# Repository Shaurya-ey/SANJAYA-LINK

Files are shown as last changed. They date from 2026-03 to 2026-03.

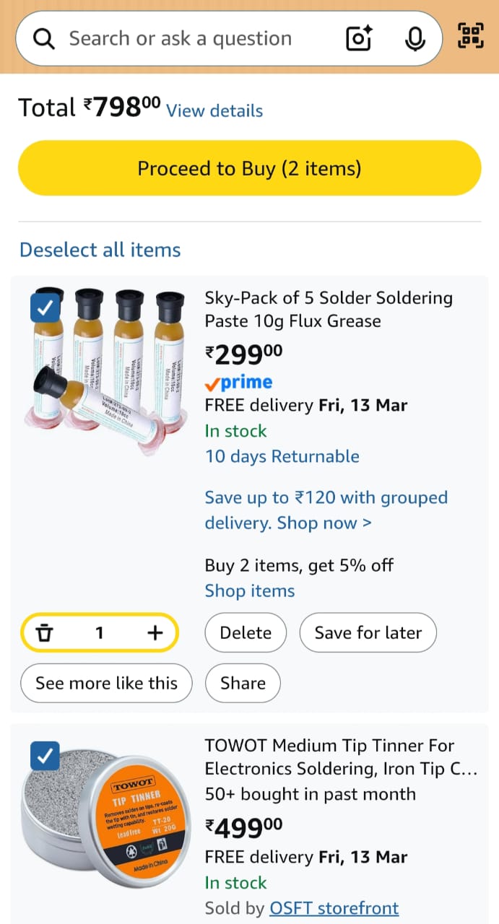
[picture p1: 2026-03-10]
Cart/amazon1.jpeg

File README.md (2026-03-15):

<h1 align="center">SANJAYA-LINK</h1>

<p align="center">
pcbfront 
pcbback
cad

</p>
 
 ---

 # 1. Overview

SANJAYA-LINK is a custom 1-Watt telemetry and control system built for drones, fixed-wing UAVs, and RC models. While ELRS and crossfire modules are great, I wanted a transparent, fully customizable dev like board based on the RP2040 and SX1262 that I could integrate directly into my own flight controllers and ground stations.

## Features
- **RP2040** – Dual-core Cortex-M0+ microcontroller running up to 133 MHz. It handles all logic and communication.
- **SX1262** – LoRa transceiver for long-range, low-power wireless communication (EU bands).
- **0900FM15K0039001E** – RF crystal oscillator for stable timing.
- **W25Q128JVS** – 128 Mbit SPI flash memory for additional storage.
- **AP2112K-3.3** – 3.3V voltage regulator.
- **PE4259** – RF switch between antenna and transceiver.
- **Status LEDs** – For easier debugging or indication.
- **Dimensions:** - 51.82mm x 48.39mm

## What it is 
This is a custom-built, compact board that pairs the **RP2040 processor** with an **SX1262 LoRa radio**.
Basically, it's a long-range wireless communicator (through Radio Signals). I designed it to be a simple way to send data over long distances without needing Wi-Fi or any other mediums.

## Why I Made This Project
I was searching a solution for telemetery of data for my upcoming **Drone** and **Model Rocketry** ideas. Then i got deep into this idea and after researching a lot i found it intresting and do-able, and decided to build this from scratch. I’ve spent a lot of time debugging things like the clock settings and power rails to make sure it actually stays running on a battery which was hectic.

## How To Use
- **Connect:** Plug the module into your computer via the USB-C port to load your code.
- **Power:** You can run it off a battery or the USB supply; I’ve included a regulator to keep the power clean and stable.
- **Lesss Goo** Just write your script, upload it, and watch it start communicating over the LoRa network.

---

# 2. Layouts

## Schematics
Schematic

## PCB

PCBrouted

## Case And Assembly

<p align="center">



---

# 3. BOM (Bill Of Materials)

| Item | Description | Quantity | Total Price (USD) | URL |
|---|---|---|---|-----|
| 100nF 0402 Capacitor | Ceramic capacitor 100nF 0402 package | 24 | 0.18 |https://robu.in/product/gcm155l8eh104ke07d-murata-electronics-50v-100nf-x8l-%c2%b110-0402-multilayer-ceramic-capacitors-mlcc-smd-smt-rohs/ |
| 1uF 0402 Capacitor | Ceramic capacitor 1uF 0402 package | 4 | 0.40 |https://www.digikey.in/en/products/detail/murata-electronics/GRM155R61H105ME05D/12091059 |
| 15pF 0402 Capacitor | Ceramic capacitor 15pF 0402 package | 5 | 0.12 |https://robu.in/product/gjm1555c1h150fb01d-murata-electronics-50v-15pf-c0g-%c2%b11-0402-multilayer-ceramic-capacitors-mlcc-smd-smt-rohs/ |
| 10uF 0402 Capacitor | Ceramic capacitor 10uF 0402 package | 4 | 1.04 | https://www.digikey.in/en/products/detail/murata-electronics/GRT155R61A106ME13D/19115561|
| 1nF 0402 Capacitor | Ceramic capacitor 1nF 0402 package | 2 | 0.28 |https://www.digikey.in/en/products/detail/kemet/C0402C102K5GECAUTO7411/8648675 |
| 39pF 0402 Capacitor | Ceramic capacitor 39pF 0402 package | 2 | 0.20 |https://www.digikey.in/en/products/detail/murata-electronics/GCM1555C1H390JA16J/4903596 |
| 3.3pF 0402 Capacitor | Ceramic capacitor 3.3pF 0402 package | 4 | 0.40 | https://www.digikey.in/en/products/detail/murata-electronics/GJM1555C1H3R3CB01D/702288|
| 470nF 0402 Capacitor | Ceramic capacitor 470nF 0402 package | 2 | 0.22 |https://www.digikey.in/en/products/detail/murata-electronics/GRM155R61A474KE15D/702528 |
| 47pF 0402 Capacitor | Ceramic capacitor 47pF 0402 package | 4 | 0.12 |https://robu.in/product/gcm1555c1h470fa16d-murata-electronics-50v-47pf-c0g-%c2%b11-0402-multilayer-ceramic-capacitors-mlcc-smd-smt-rohs/ |
| Blue LED 0402 | Blue indicator LED | 2 | 0.38 |https://www.digikey.in/en/products/detail/w%C3%BCrth-elektronik/150080BS75000/4489912 |
| Red LED 0402 | Red indicator LED | 2 | 0.38 |https://www.digikey.in/en/products/detail/w%C3%BCrth-elektronik/150080SS75000/4489921 |
| BLM15AX102SN1D | Ferrite bead 1kΩ @100MHz 0402 | 2 | 0.20 | https://www.digikey.in/en/products/detail/murata-electronics/BLM15AX102SN1D/2256877|
| 0900FM15K0039001E | LoRa RF front-end filter | 2 | 0.90 |https://www.digikey.in/en/products/detail/johanson-technology-inc/0900FM15K0039001E/16639329 |
| USB-C Port | USB Type-C receptacle | 2 | 1.54 |https://www.digikey.in/en/products/detail/gct/USB4105-GF-A/11198441 |
| SMA Connector | RF antenna connector | 2 | 6.56 |https://www.digikey.in/en/products/detail/taoglas-limited/EMPCB-SMAFSTJ-B-HT/3522337 |
| 15uH 0402 Inductor | Power inductor 15uH | 2 | 0.12 |https://www.digikey.in/en/products/detail/murata-electronics/LQW15DN150M00D/9559544 |
| 47nH 0402 Inductor | RF inductor 47nH | 2 | 0.20 | https://www.digikey.in/en/products/detail/murata-electronics/LQG15WH47NJ02D/11690059|
| 9.1nH 0402 Inductor | RF inductor 9.1nH | 4 | 0.13 |https://robu.in/product/lqw15an9n1g00d-murata-wirewound-inductor-9-1-nh-0-14-ohm-5-5-ghz-540-ma-0402-1005-metric-lqw15a_00/ |
| 100Ω 0402 Resistor | Resistor 100Ω | 2 | 0.20 | https://www.digikey.in/en/products/detail/yageo/RC0402FR-10100RL/16982189|
| 10kΩ 0402 Resistor | Resistor 10kΩ | 2 | 0.20 |https://www.digikey.in/en/products/detail/yageo/RT0402FRD0710KL/5926329 |
| 27.4Ω 0402 Resistor | Resistor 27.4Ω | 4 | 0.40 |https://www.digikey.in/en/products/detail/bourns-inc/CR0402-FX-27R4GLF/3783281 |
| 1kΩ 0402 Resistor | Resistor 1kΩ | 8 | 0.79 |https://www.digikey.in/en/products/detail/yageo/RC0402FR-071KL/726513 |
| 5.1kΩ 0402 Resistor | Resistor 5.1kΩ | 4 | 0.40 |https://www.digikey.in/en/products/detail/yageo/RC0402FR-135K1L/14286364 |
| Tactile Switch | Reset / Boot tactile switch | 4 | 0.88 |https://www.digikey.in/en/products/detail/same-sky-formerly-cui-devices/TS09-63-25-WT-260-SMT-TR/15839064 |
| SX1262IMLTRT | LoRa transceiver IC | 2 | 6.22 |https://robu.in/product/sx1262imltrt-semitech-300kbps-general-purposeism1ghz-spi-qfn-24-ep4x4-rf-transceiver-ics-rohs/ |
| RP2040 | Microcontroller | 2 | 1.74 |https://robu.in/product/raspberry-pi-rp2040/ |
| W25Q64JVSSIQ | SPI Flash memory | 2 | 4.40 |https://robu.in/product/w25q64jvssiq-winbond-elec-sop-8-208mil-nor-flash-rohs/ |
| AP2127K-3.3 | 3.3V LDO regulator | 2 | 0.38 |https://www.digikey.in/en/products/detail/diodes-incorporated/AP2127K-3-3TRG1/4470786 |
| RF Switch SPDT | RF switch SC70-6 | 2 | 1.56 |https://www.digikey.in/en/products/detail/psemi/4259-63/2614473 |
| 32MHz Crystal | System clock crystal | 2 | 0.88 | https://robu.in/product/yxc-ysx221sl-32mhz-12pf-20ppm-4pad-smd-smt-crystal/|
| 12MHz Crystal | System clock crystal | 2 | 0.40 |https://robu.in/product/ysx321sl-12mhz-10pf-10ppm-4pins-smd-smt-metal-surface-quartz-crystal-pack-of-2/ |
| Schottky Diode | Fast switching diode | 2 | 0.46 |https://www.digikey.in/en/products/detail/mcc-micro-commercial-components/MBR0520-TP/717250 |
| USBLC6-2SC6 | USB ESD protection | 2 | 0.70 | https://www.digikey.in/en/products/detail/stmicroelectronics/USBLC6-2SC6/1040559|
| TPD1E05U06 | ESD protection diode | 2 | 0.70 | https://www.digikey.in/en/products/detail/texas-instruments/TPD1E05U06DPYR/3844805|
| MF-MSMF050 | Resettable fuse | 2 | 1.02 | https://www.digikey.in/en/products/detail/bourns-inc/MF-MSMF050-30X-2/15926789|
| Header Pins | Pin headers | 2 | 0.13 |https://robu.in/product/2-54mm-1x40-pin-male-single-row-straight-short-header-strip-pack-of-3/ |
| 865–868MHz Antenna | Rubber duck antenna | 1 | 0.69 | https://robu.in/product/865-868mhz-1-8-dbi-gain-rubber-duck-antenna/|
| Solder Wire | Soldering wire | 1 | 3.30 | https://robu.in/product/soldering-wire-1-mm-100g/|
| Soldering Flux | Flux for soldering | 1 | 3.24 |https://www.amazon.in/dp/B08VHD1VS1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 |
| Tip Tinner | Soldering tip cleaner | 1 | 5.41 |https://www.amazon.in/dp/B09BQRQ9JF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 |
| Hot Air Station | YIHUA 8858-IV portable | 1 | 25.09 |https://robu.in/product/yihua-8858-iv-portable-hot-air-station/ |
| PCB Manufacturing + 3-D Printing | Printed circuit board + 3d printing | 1 | 24.14 + 2 | |
| 2.5x10mm Screws | Screws for Case | 1 | 1.52 | https://robu.in/product/easymech-ss-304-csk-countersunk-philips-head-m2-5-x-6-mm-bolt-25-pcs/ |
| **Shipping** | **Shipping fee** | 1 | 13.01 | |
| **TOTAL** |  |  | **116.17 USD** | |

# Note:
- I want some Soldering items + Heat gun for Soldering SMD components (as Assembly as a option for PCB Manufacturing is very costly + there will be hefty custom fees on them for 2 assembled boards), that i've included in BOM.
- I've included everything including Total Shipping Fee and Cart screen shots in the BOM.
- I'm building 2 LoRa boards so that i can verify and use them in my future projects.

**Thank You!!**

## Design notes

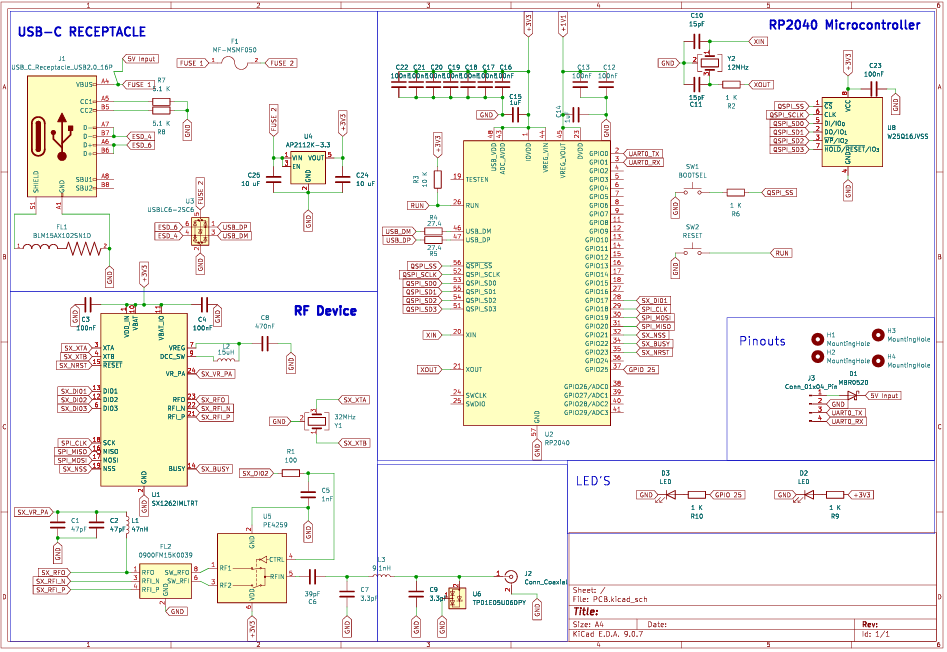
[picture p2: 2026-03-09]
Schematic.PNG

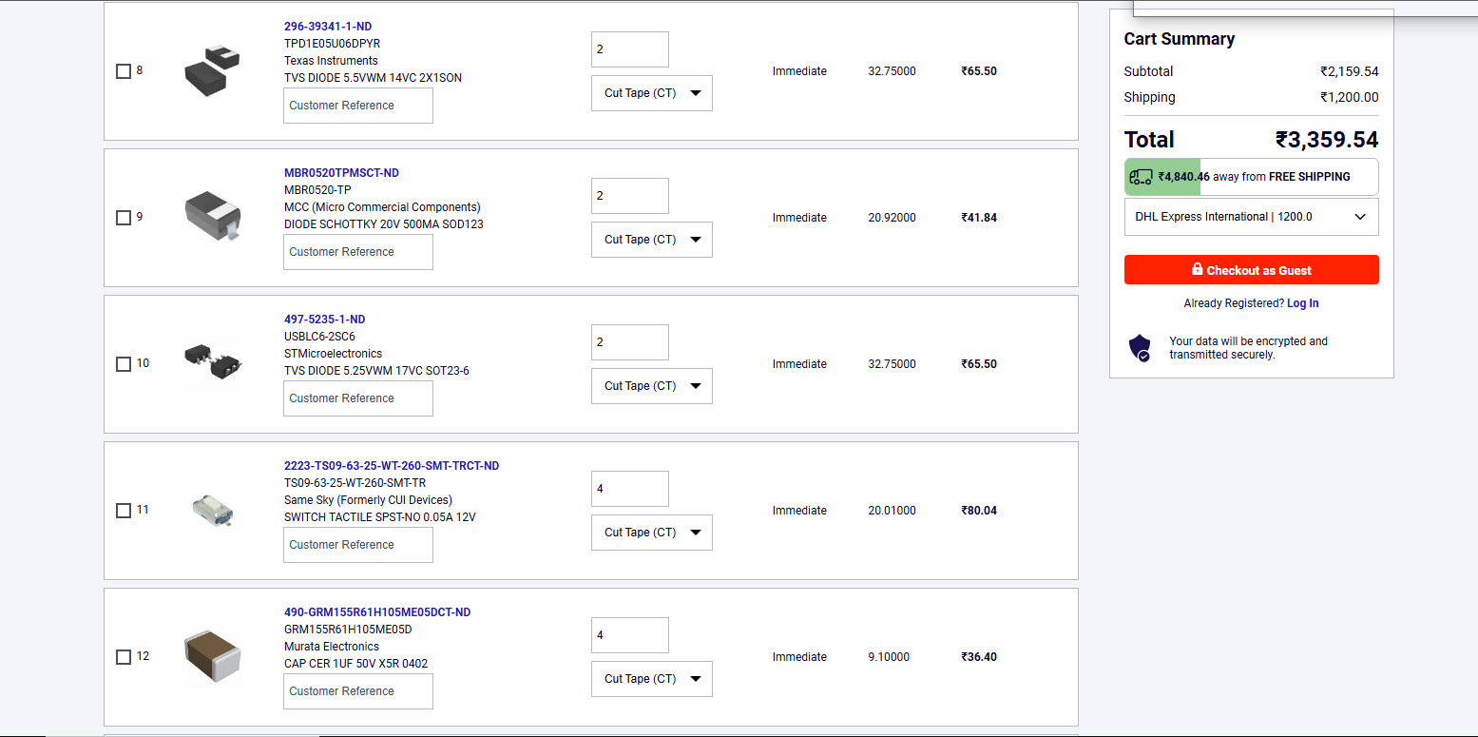
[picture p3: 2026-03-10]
Cart/d3.PNG

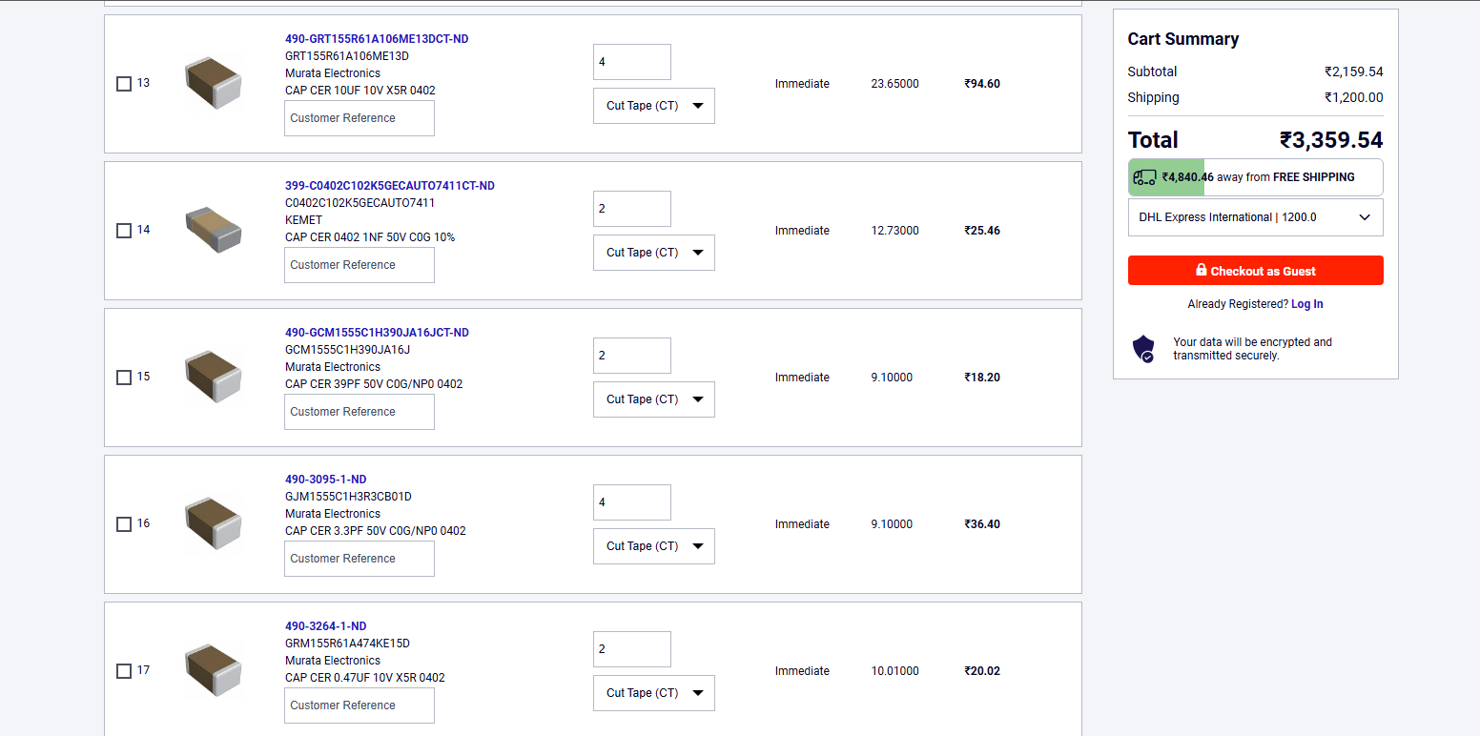
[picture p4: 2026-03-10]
Cart/d4.PNG

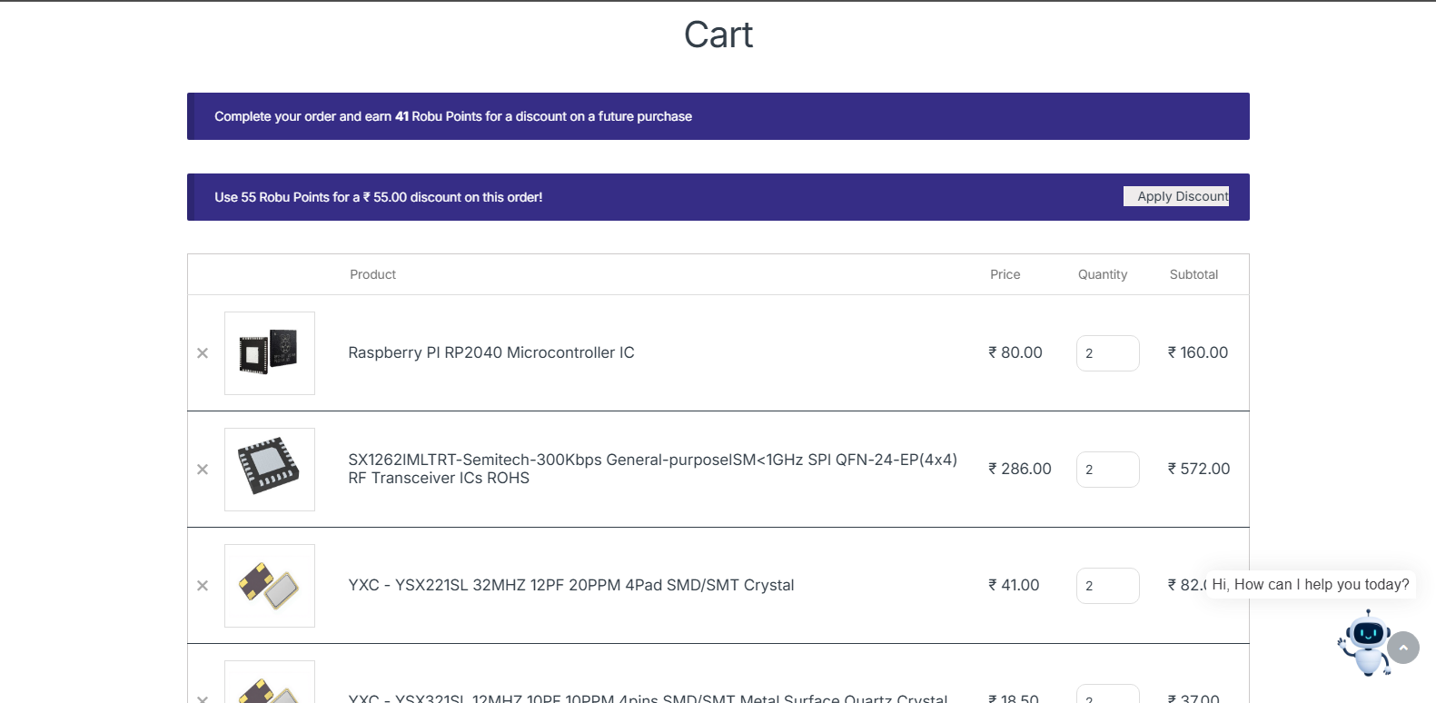
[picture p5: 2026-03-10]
Cart/r1.PNG

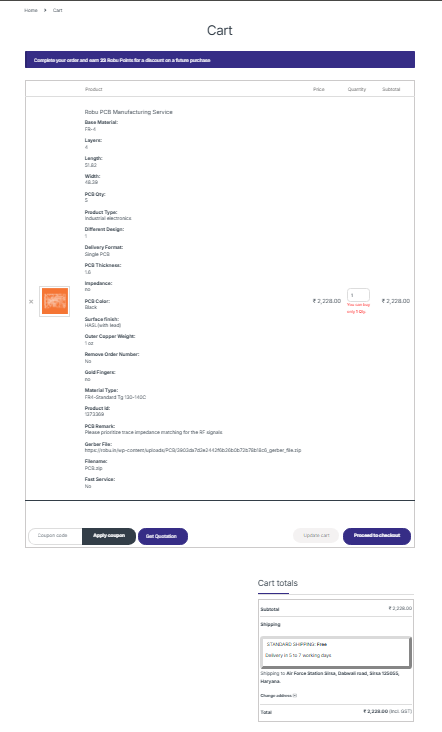
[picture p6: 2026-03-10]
Cart/rpcb.PNG

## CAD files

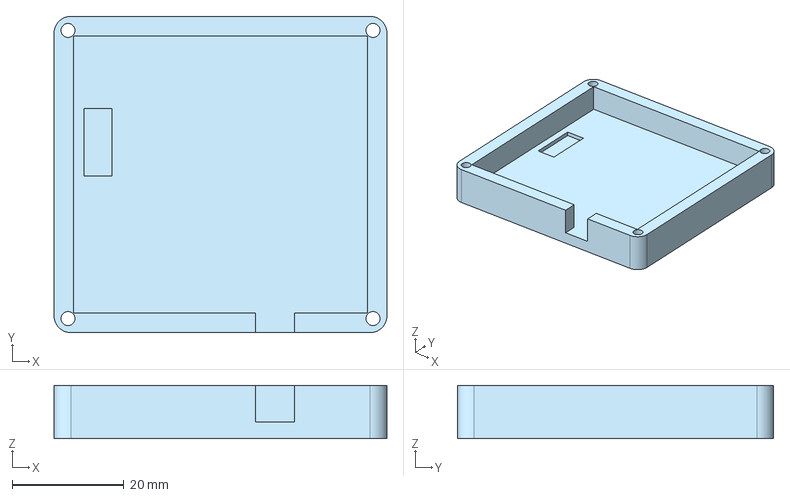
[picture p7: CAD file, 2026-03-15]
CAD/LoRa Case Bottom.step
59.5 x 56.5 x 9.50 mm

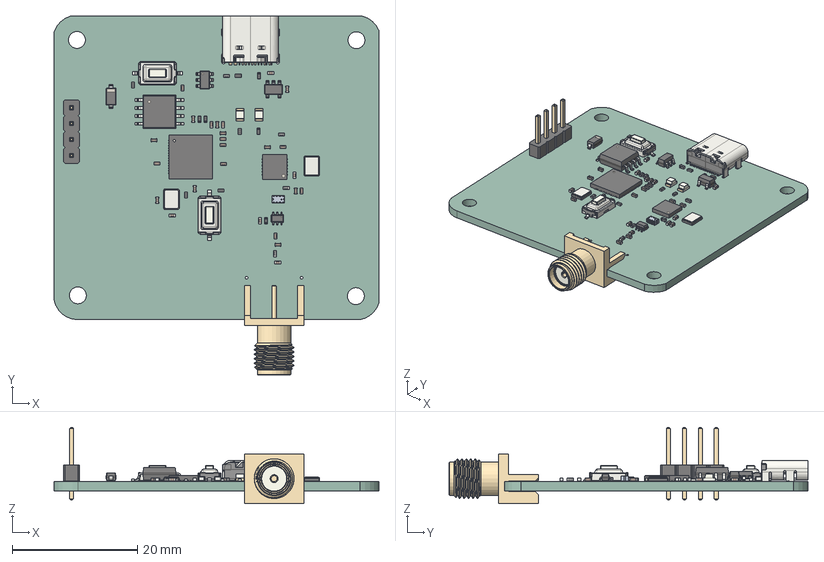
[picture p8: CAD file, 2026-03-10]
PCB/PCB.step
51.8 x 57.2 x 12.1 mm
C_0402_1005Metric x 25
R_0402_1005Metric x 10
USB_C_Receptacle_GCT_USB4105-xx-A_16P_TopMnt_Horizontal
L_0402_1005Metric x 4
QFN-56-1EP_7x7mm_P0.4mm_EP3.2x3.2mm
SOT-23-5
SOT-363_SC-70-6
LED_0805_2012Metric x 2
QFN-24-1EP_4x4mm_P0.5mm_EP2.6x2.6mm
SOT-23-6
Crystal_SMD_Abracon_ABM8G-4Pin_3.2x2.5mm
D_SOD-123
PinHeader_1x04_P2.54mm_Vertical
SMA_Molex_73251-1153_EdgeMount_Horizontal
SW_Tactile_SPST_NO_Straight_CK_PTS636Sx25SMTRLFS x 2
Crystal_SMD_3225-4Pin_3.2x2.5mm
PCB 1.48.1
PCB 1.48.2
PCB 1.48.3
SOIC-8_5.3x5.3mm_P1.27mm
PCB_PCB

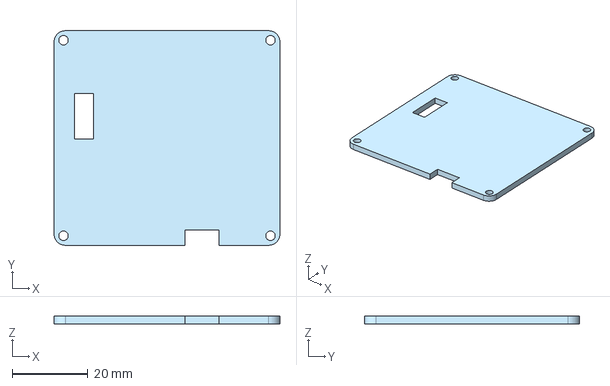
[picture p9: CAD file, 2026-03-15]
CAD/LoRa Case Top.step
59.5 x 56.5 x 2.00 mm

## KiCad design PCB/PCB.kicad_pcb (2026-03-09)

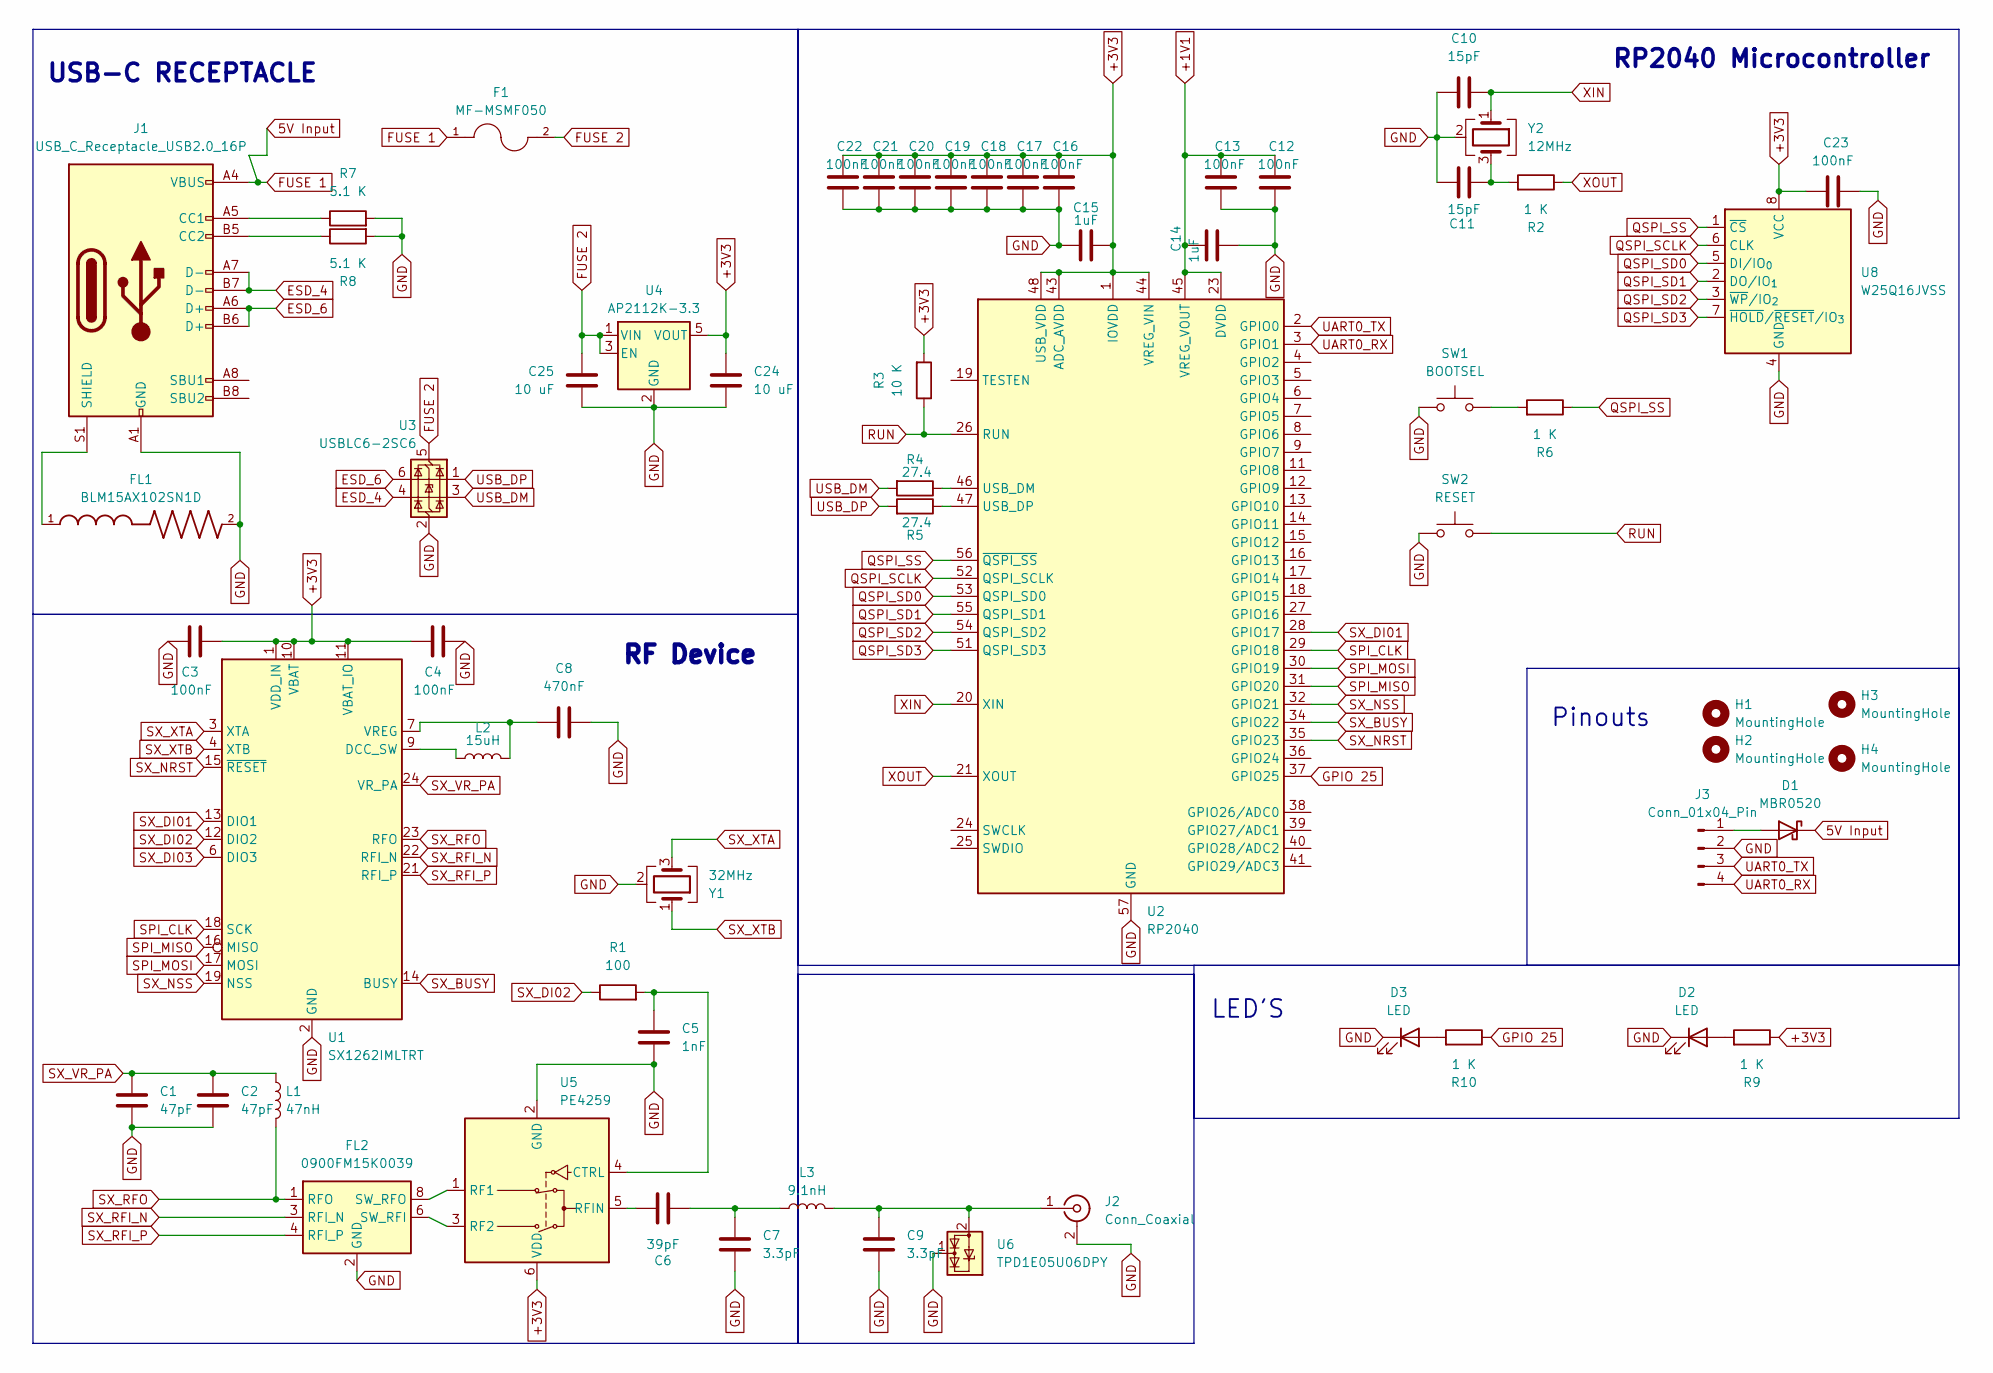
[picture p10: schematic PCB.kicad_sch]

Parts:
C1, C2: 47pF; C_0402_1005Metric
C3, C4, C12, C13, C16, C17, C18, C19, C20, C21, C22, C23: 100nF; C_0402_1005Metric
C5: 1nF; C_0402_1005Metric
C6: 39pF; C_0402_1005Metric
C7, C9: 3.3pF; C_0402_1005Metric
C8: 470nF; C_0402_1005Metric
C10, C11: 15pF; C_0402_1005Metric
C14, C15: 1uF; C_0402_1005Metric
C24, C25: 10 uF; C_0402_1005Metric
D1: MBR0520; D_SOD-123
D2, D3: LED; LED_0805_2012Metric
F1: MF-MSMF050; FUSER_MF-MSMF050
FL1: BLM15AX102SN1D; L_0402_1005Metric
FL2: 0900FM15K0039; Balun_Johanson_0900FM15K0039
H1, H2, H3, H4: MountingHole; MountingHole_2.7mm_M2.5_Pad
J1: USB_C_Receptacle_USB2.0_16P; USB_C_Receptacle_GCT_USB4105-xx-A_16P_TopMnt_Horizontal
J2: Conn_Coaxial; SMA_Molex_73251-1153_EdgeMount_Horizontal
J3: Conn_01x04_Pin; PinHeader_1x04_P2.54mm_Vertical
L1: 47nH; L_0402_1005Metric
L2: 15uH; L_0402_1005Metric
L3: 9.1nH; L_0402_1005Metric
R1: 100; R_0402_1005Metric
R2, R6, R9, R10: 1 K; R_0402_1005Metric
R3: 10 K; R_0402_1005Metric
R4, R5: 27.4; R_0402_1005Metric
R7, R8: 5.1 K; R_0402_1005Metric
SW1: BOOTSEL; SW_Tactile_SPST_NO_Straight_CK_PTS636Sx25SMTRLFS
SW2: RESET; SW_Tactile_SPST_NO_Straight_CK_PTS636Sx25SMTRLFS
U1: SX1262IMLTRT; QFN-24-1EP_4x4mm_P0.5mm_EP2.6x2.6mm
U2: RP2040; QFN-56-1EP_7x7mm_P0.4mm_EP3.2x3.2mm
U3: USBLC6-2SC6; SOT-23-6
U4: AP2112K-3.3; SOT-23-5
U5: PE4259; SOT-363_SC-70-6
U6: TPD1E05U06DPY; Texas_DPY0002A_0.6x1mm_P0.65mm
U8: W25Q16JVSS; SOIC-8_5.3x5.3mm_P1.27mm
Y1: 32MHz; Crystal_SMD_3225-4Pin_3.2x2.5mm
Y2: 12MHz; Crystal_SMD_Abracon_ABM8G-4Pin_3.2x2.5mm

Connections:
5V Input: D1.1 (K), F1.1, J1.A4 (VBUS), J1.A9 (VBUS), J1.B4 (VBUS), J1.B9 (VBUS)
+1V1: C12.2, C13.2, C14.2, U2.23 (DVDD), U2.45 (VREG_VOUT), U2.50 (DVDD)
+3V3: C3.2, C4.1, C15.2, C16.2, C17.2, C18.2, C19.2, C20.2, C21.2, C22.2, C23.1, C24.1, R3.2, R9.1, U1.1 (VDD_IN), U1.10 (VBAT), U1.11 (VBAT_IO), U2.1 (IOVDD), U2.10 (IOVDD), U2.22 (IOVDD), U2.33 (IOVDD), U2.42 (IOVDD), U2.43 (ADC_AVDD), U2.44 (VREG_VIN), U2.48 (USB_VDD), U2.49 (IOVDD), U4.5 (VOUT), U5.6 (VDD), U8.8 (VCC)
ESD_4: J1.A7 (D-), J1.B7 (D-), U3.4 (I/O2)
ESD_6: J1.A6 (D+), J1.B6 (D+), U3.6 (I/O1)
FUSE 2: C25.1, F1.2, U3.5 (VBUS), U4.1 (VIN), U4.3 (EN)
GND: C1.2, C2.2, C3.1, C4.2, C5.2, C7.2, C8.2, C9.2, C10.1, C11.1, C12.1, C13.1, C14.1, C15.1, C16.1, C17.1, C18.1, C19.1, C20.1, C21.1, C22.1, C23.2, C24.2, C25.2, D2.1 (K), D3.1 (K), FL1.2, FL2.2 (GND), FL2.5 (GND), FL2.7 (GND), FL2.9 (GND), FL2.10 (GND), J1.A1 (GND), J1.A12 (GND), J1.B1 (GND), J1.B12 (GND), J2.2 (Ext), J3.2, R7.2, R8.2, SW1.1, SW2.1, U1.2 (GND), U1.5 (GND), U1.8 (GND), U1.20 (GND), U1.25 (GND), U2.57 (GND), U3.2 (GND), U4.2 (GND), U5.2 (GND), U6.1 (I/O), U8.4 (GND), Y1.2 (G), Y1.4 (G), Y2.2 (G), Y2.4 (G)
GPIO 25: R10.1, U2.37 (GPIO25)
unnamed: C6.2, C7.1, L3.1
unnamed: C11.2, R2.2, Y2.3
unnamed: D1.2 (A), J3.1
unnamed: D2.2 (A), R9.2
unnamed: D3.2 (A), R10.2
unnamed: FL2.6 (SW_RFI), U5.3 (RF2)
unnamed: FL2.8 (SW_RFO), U5.1 (RF1)
unnamed: J1.A5 (CC1), R7.1
unnamed: J1.B5 (CC2), R8.1
unnamed: FL1.1, J1.S1 (SHIELD)
unnamed: C9.1, J2.1 (In), L3.2, U6.2 (GND)
unnamed: R6.2, SW1.2
unnamed: L2.1, U1.9 (DCC_SW)
unnamed: C8.1, L2.2, U1.7 (VREG)
unnamed: R4.1, U2.46 (USB_DM)
unnamed: R5.1, U2.47 (USB_DP)
unnamed: C5.1, R1.2, U5.4 (CTRL)
unnamed: C6.1, U5.5 (RFIN)
QSPI_SCLK: U2.52 (QSPI_SCLK), U8.6 (CLK)
QSPI_SD0: U2.53 (QSPI_SD0), U8.5 (DI/IO_{0})
QSPI_SD1: U2.55 (QSPI_SD1), U8.2 (DO/IO_{1})
QSPI_SD2: U2.54 (QSPI_SD2), U8.3 (~WP/IO_{2})
QSPI_SD3: U2.51 (QSPI_SD3), U8.7 (~HOLD/~RESET/IO_{3})
QSPI_SS: R6.1, U2.56 (~QSPI_SS), U8.1 (~CS)
RUN: R3.1, SW2.2, U2.26 (RUN)
SPI_CLK: U1.18 (SCK), U2.29 (GPIO18)
SPI_MISO: U1.16 (MISO), U2.31 (GPIO20)
SPI_MOSI: U1.17 (MOSI), U2.30 (GPIO19)
SX_BUSY: U1.14 (BUSY), U2.34 (GPIO22)
SX_DI01: U1.13 (DIO1), U2.28 (GPIO17)
SX_DI02: R1.1, U1.12 (DIO2)
SX_DI03: U1.6 (DIO3)
SX_NRST: U1.15 (~RESET), U2.35 (GPIO23)
SX_NSS: U1.19 (NSS), U2.32 (GPIO21)
SX_RFI_N: FL2.3 (RFI_N), U1.22 (RFI_N)
SX_RFI_P: FL2.4 (RFI_P), U1.21 (RFI_P)
SX_RFO: FL2.1 (RFO), L1.2, U1.23 (RFO)
SX_VR_PA: C1.1, C2.1, L1.1, U1.24 (VR_PA)
SX_XTA: U1.3 (XTA), Y1.3
SX_XTB: U1.4 (XTB), Y1.1
UART0_RX: J3.4, U2.3 (GPIO1)
UART0_TX: J3.3, U2.2 (GPIO0)
USB_DM: R4.2, U3.3 (I/O2)
USB_DP: R5.2, U3.1 (I/O1)
XIN: C10.2, U2.20 (XIN), Y2.1
XOUT: R2.1, U2.21 (XOUT)

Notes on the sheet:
LED'S
RF Device
RP2040 Microcontroller
USB-C RECEPTACLE
Pinouts

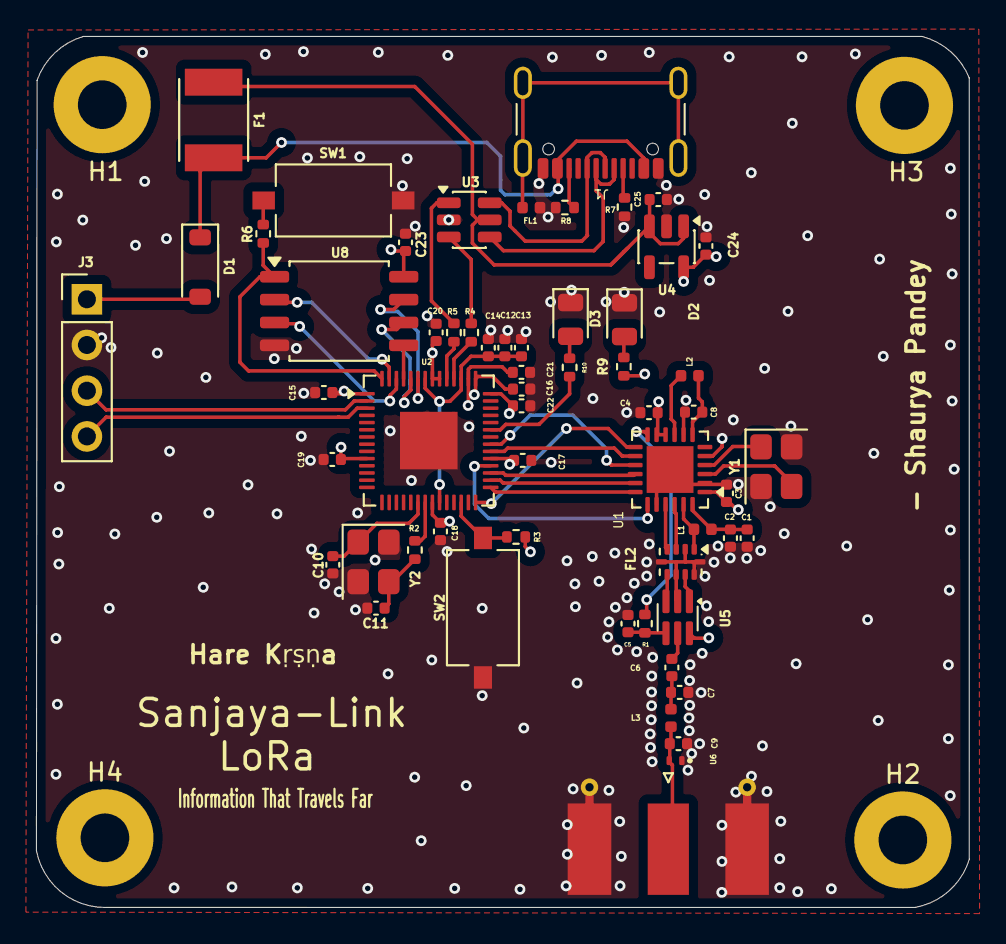
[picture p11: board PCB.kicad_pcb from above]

Board: 4 copper layers, 51.8 x 48.4 mm, 62 parts (0 on the bottom side), 53 nets.

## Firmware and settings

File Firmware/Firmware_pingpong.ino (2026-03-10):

#include <RadioLib.h>


#define LORA_NSS  17   
#define LORA_BUSY 13   
#define LORA_RST  12   
#define LORA_DIO1 14   


SX1262 radio = new Module(LORA_NSS, LORA_DIO1, LORA_RST, LORA_BUSY);

void setup() {
  Serial.begin(115200);
  delay(2000); 

  Serial.println(F("[SX1262] Initializing ... "));

  
  int state = radio.begin(868.0); 

  if (state == RADIOLIB_ERR_NONE) {
    Serial.println(F("Success! SPI Communication is working."));
  } else {
    Serial.print(F("Failed, code "));
    Serial.println(state);
    while (true); 
  }
}

void loop() {
  Serial.print(F("[SX1262] Sending test packet ... "));


  int state = radio.transmit("Hello World!");

  if (state == RADIOLIB_ERR_NONE) {
    Serial.println(F("Packet sent successfully!"));
  } else if (state == RADIOLIB_ERR_TX_TIMEOUT) {
    Serial.println(F("Timed out - check your antenna connection."));
  } else {
    Serial.print(F("Failed, code "));
    Serial.println(state);
  }

  
  delay(5000);
}

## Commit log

2026-03-09 Add schematic image to README
2026-03-10 Update README with schematic and clean up images
    Added schematic image to README and removed duplicate PCB images.
2026-03-10 Fix image tag for pcbback in README
    Updated image tag for pcbback in README.md.
2026-03-10 Replace back PCB image in README
